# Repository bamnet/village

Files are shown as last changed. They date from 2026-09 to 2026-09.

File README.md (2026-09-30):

# Village Electric Light Department

_(village, for short)_

## Background

I have a collection of 1-2 dozen Department 56 lighted Christmas houses. The default
lighting solution has a big problem though: a house is either lit or not. Further,
the default technique of daisy-chaining all of the plugs together means the entire
village is typically on or off.

This is not very realistic, our winter Dickens Village is not North Korea.

## Goal

The Village Electric Light Department provides the ability for each house to be
individually dimmed and to have that brightness vary throughout the night. This
enables much more custom and realistic displays, with each house following its
own lighting pattern throughout the night and across different nights.

## Approach

### 2018?

In 2018 we built our first prototype. To do this, we bought an RGB LED strip and cut
it into individual segments. We soldered wires onto each segment, and wired them all
back into a TLC5947 controlled by an ESP32.

Each house got one cut segment of a 12 V analog (not individually addressable) RGBW
strip (Shiji Lighting SJ-10060-RGBW, 60 LEDs/m). A segment has 3 warm-white 5050 RGBW
LEDs. Each color channel runs its 3 LEDs in series with a current-limiting resistor
(150 ohm on G/B/W), roughly 20 mA per channel. The TLC5947 sank each channel's
current. See `archive/2018_led_segment.jpg`.

This was a good proof of concept, but the construction was quite messy with flexible
LED strip segments haphazardly positioned in the back / bottom lighting holes of the
houses, a messy breadboard wiring this all together, and standalone power supply.

### 2020?

We started cleaning up this design by introducing a circular PCB with LEDs that we
could fit into a 3D printer holder for each house. These could, in theory, be wired
back to a base station for control.

Ultimately, we never finished a working end-to-end design here, largely driven by
the manual work to solder connectors onto each of the PCBs and, more importantly,
the manual work to build custom cables to connect the PCBs back to the base station.

### 2025

We specified a two-board design (ESP32-S3 base station running WLED, plus a
daisy-chained 20 mm Pixel PCB with SK6812 RGBW LEDs) and started a controller
layout. Nothing was fabricated because we ran out of time.

## Specifications

Requirement keywords (MUST, SHOULD, MAY) follow RFC 2119. Items marked **TBD** are
open decisions.

### System

- The system MUST support 22 houses.
- Each house MUST be independently addressable, so its brightness can be set on
  its own. Addressing each LED within a house MAY be supported, but is not required.
- Houses SHOULD be daisy-chained, with the base station driving about 4 chains
  (roughly 6 houses per chain). This keeps cables short and the base station tidy.
  It is a preference, not a hard requirement: another topology is acceptable if
  it is clearly better.

### Physical layout

- Tentatively, the base station sits in the middle, between two shelves, with chains
  running outward on both sides.
- Houses are spaced about 1 ft (0.3 m) apart. A house-to-house cable of about 1 m
  gives enough slack.
- The farthest house is no more than 8 ft (2.4 m) from the base station.

### Light

As a winter village, each house MUST be lit using warm white light. Each house MAY
support RGB to fine tune the colors and do neat patterns.

The light should be bright, historically using a 5 - 6 watt C7 bulb @ 120 volts.
We obviously want to modernize this with an LED.

- Research (2026-09) shows small incandescent C7 bulbs are dim. Retail listings give
  a 4 W clear C7 as 16 - 19 lm, and a 5 W, 130 V-rated C7 as about 10 lm. LED
  "5 W equivalent" C7 bulbs claim 50 - 75 lm, but those figures are marketing, not
  measurements. The 2025 spec's "~60 lm" target is probably 3x too high.
- The 2018 prototype segment was bright enough, even with its poor LED placement on
  a flexible strip. It had 3 warm-white RGBW 5050 LEDs per house, each channel's LEDs
  in series at about 20 mA.
- Brightness target: warm-white output per house SHOULD match the 2018 segment,
  meaning 3 warm-white RGBW 5050 LEDs driven at about 16 - 20 mA.
- Each house MUST use one WS2814 as its driver. It is a 4-channel RGBW
  constant-current driver that WLED supports (configured as SK6812 RGBW type). Its
  outputs are fixed at 16.5 mA per channel, about 80% of the 2018 current.
  **TBD:** confirm this is bright enough.
- As of 2026-09-30, the original SOP-12 WS2814 (C965562) shows 0 stock at LCSC.
  The draft schematic uses the WS2814F (FSOP-8, C5446694, about 107,000 in stock).
  It has the same 16.5 mA outputs, the same 9 V DIN rating, and the same 12 V
  application circuit (2.7k to VDD, 0.1 uF). It has no backup data input (DIN2),
  so there is nothing to tie off. Its data order is W, R, G, B (datasheet p. 4).
  The WS2814A (SOP-8, C2920044, about 7,800 in stock) is the same die in a larger
  package. It is the fallback, with a standard SOIC-8 footprint.
- Decided (2026-09-30): the Pixel PCB uses the WS2814F. Its smaller body leaves
  more room for the LEDs on the 20 mm board.
- The WS2814F's FSOP-8 footprint (1.65 x 3.25 mm body, 2.85 mm lead span, 0.8 mm
  pitch) is not in KiCad's stock libraries, so we drew it. Once it's proven on a fabricated
  board, consider contributing it (and a WS2814 symbol) upstream to the KiCad
  libraries.
- Each channel drives 3 LEDs in series, and all 3 LEDs show the same color, with one
  address per house. The white channel MUST be warm white (2700 - 3000 K).
- LEDs SHOULD be 3 RGBW 5050 4-in-1 packages with a warm-white die, matching 2018.
  Fallback: 3 RGB LEDs plus 3 separate warm-white LEDs, which also allows a free
  choice of warm-white LED.
- As of 2026-09, LCSC has two warm-white 4-in-1 RGBW 5050 parts (SMD5050-8P, with
  a separate anode and cathode pin per color). Both are JLCPCB extended parts.
  Figures are from the datasheets, at 20 mA:
  - Honglitronic HL-5050RGBW-S1-A27 (C22470444): about 11,000 in JLCPCB stock.
    The "-A27" suffix is the datasheet's white bin A27, which is 2580 - 2870 K.
    That is slightly warmer than 2700 - 3000 K at the low end. White gives 7 - 9 lm,
    CRI 80 or better. Forward voltage is 2.8 - 3.4 V (W/G/B) and 1.8 - 2.4 V (R).
  - TCWIN TC5050RGBW3D06-4CSAR3-AFW324A (C784543): 2800 - 3200 K. White gives
    6 - 7 lm, CRI 80 - 85, with a forward voltage of 2.8 - 3.2 V. Stock is low
    (about 240 at JLCPCB, 860 at LCSC).
  - Cool-white variants that do not meet the spec: XINGLIGHT XL-5050RGBW
    (C7371891), TCWIN C784545 (6000 - 6500 K), and C784544 (3800 - 4200 K).
  **TBD:** choose between them. The Honglitronic part is preferred. One caution:
  its spec sheet (B-18-A-1651 rev A/2, 2019) has "Under Development" checked on
  its cover, not "Mass production". JLCPCB stocks it, so this is probably stale
  paperwork, but weigh it against TCWIN once the samples arrive.
- Heat is not expected to be a concern. The cut-up LED strip prototype ran without
  heat problems.
- Driver heat (estimated): 3 red LEDs drop only 5.4 - 7.2 V, which leaves up to
  about 6.6 V across the WS2814's red output (about 110 mW at 16.5 mA). The draft
  adds a 120 ohm ballast resistor (R4) on red to take about 2 V (33 mW) of that off
  the chip. With all four channels at full, the WS2814 then dissipates about
  0.2 W worst case. Warm-white-only use is well below this.
- The two LED candidates have different pinouts. Honglitronic has anodes on pins
  1/3/5/7 (W/B/G/R) and cathodes on 2/4/6/8. TCWIN has anodes on 1-4 (R/G/B/W)
  and cathodes on 8-5. The draft schematic follows the Honglitronic part.

### Interconnect

The lack of a practical cable solution is what stalled the 2020 attempt, so it is a
first-class requirement here.

- Cables MUST be off-the-shelf or easily purchasable. We MUST NOT need to crimp,
  solder, or otherwise build our own cables (the system needs about 24 of them).
- House-to-house links need cables of about 1 m. **TBD:** the length from the base
  station to the first house in each chain.
- The WS2814 datasheet specifies data runs of up to 2 m between two points without
  extra circuitry. The base-station-to-first-house run SHOULD stay within about 2 m.
  Otherwise the base station needs a stronger line driver.
- Cables MUST be standard 3-wire RC servo extension cables (JR/Futaba style, 2.54 mm
  pitch), bought ready-made. 1 m male-to-female cables are widely sold. 22 AWG is
  preferred over 26 AWG for lower voltage drop.
- Boards MUST use 2.54 mm pitch 1x3 headers: male pins for the incoming cable and a
  female socket for the outgoing cable. JLCPCB solders these through-hole parts.
- Pinout MUST put power on the middle pin, following the servo convention. Then a
  reversed plug swaps ground and data rather than shorting the supply. The design
  SHOULD tolerate a reversed plug without damage, using series resistors on data
  lines and similar measures. This is to be verified during design: in a reversal,
  a house's ground rides on the upstream data line, and the WS2814 data input is
  rated to only 9 V.
- Draft protection (Pixel PCB schematic v0.1, estimated rather than tested):
  - Reversed plug: this house's GND pin lands on the upstream data line. The
    return current of this house and every house downstream is about 2.6 mA per
    house through its 2.7k VDD resistor, so about 16 mA for 6 houses, since the
    LEDs stay dark with no valid data. Most of it flows through the upstream
    house's R3 (100 ohm) into the upstream WS2814's DOUT. For the first house in
    a chain, it flows into the Dig-Quad's output buffer instead. Only about
    1 - 2 mA goes through this house's R2 (1k) and D1. The part at risk is
    therefore the upstream driver. The datasheet rates DOUT sink current at 10 mA
    minimum at 0.4 V (p. 3), which is less than 16 mA. While the upstream DOUT is
    high, this house's ground rises to about 5 V. The current then splits between
    R2/D1 (about 5 mA) and the upstream chip's VDD. D1's job is to clamp DIN so it
    can't go below this house's lifted GND.
  - Offset plug (a socket shifted one pin over on the header): 12 V can land on the
    data pin. R2 limits this to about 7 mA into VDD through D1, so R2 dissipates
    about 45 mW (the 0402 is rated 62.5 mW). The pass/fail limit is the datasheet's
    VDD absolute maximum of 3.7 - 5.3 V (p. 2), so VDD must stay at or below 5.3 V.
  - Why keep D1: the datasheet limits logic input voltage to "VDD-0.7 ~ VDD+0.7"
    (p. 2). The lower bound is almost certainly a typo for -0.7 V. Either way, DIN
    may go only about 0.7 V beyond the rails. The BAT54S (Vf about 0.3 V) keeps
    DIN inside that window in both the reversed and offset cases. A series
    resistor alone would not.
  - DOUT keeps the datasheet's 100 ohm series resistor.
  - **TBD:** the R2 value. Test on the first fabricated Pixel boards (the LED
    samples on order don't include a WS2814F):
    - Reversed plug: check that the upstream DOUT and the Dig-Quad output survive
      and still work afterward.
    - Offset plug: measure VDD with 12 V on DATA_IN. It must stay at or below 5.3 V.
    No circuit change is planned until those results are in.
- Flat servo cable fits the original cord channel. It is thinner than the classic
  120 V lamp cord that already uses it.

### Power

- The system MUST use a 12 V supply. We chose 12 V over 5 V because of voltage drop.
  5 V SK6812 LEDs need at least 4.5 V at the last house, which leaves only about
  0.5 V for losses across a chain of servo cables. At 12 V, 3 white/blue/green LEDs
  in series need about 9 - 9.6 V (3.0 - 3.2 V each). Allowing for the driver output,
  that leaves roughly 1.5 V of headroom. These are estimates: the WS2814 datasheet
  does not specify the minimum output voltage it needs to regulate.
- Estimated load: about 66 mA per house with all four channels at full, so about 1.5 A
  (18 W) for 22 houses. With warm white only, it is about 16.5 mA per house, so about
  0.4 A.
- Estimated voltage drop: about 0.6 V at full RGBW for a 6-house chain on 26 AWG
  cable (about 2 m to the first house, then 1 m hops). This is within the headroom.
- For the prototype, power enters through the Dig-Quad's input screw terminals.
  **TBD:** a supply sized with margin (for example 12 V, 3 A or more).

### Pixel PCB

- The project targets KiCad 10. Files saved in KiCad 10 cannot be opened in
  KiCad 9.
- Draft schematic: `hardware/pixel/pixel.kicad_sch` (v0.1). It was authored in
  KiCad 9 format and is ERC clean in KiCad 9.0.2 and 10.0.6.
- Custom footprints live in the project library `hardware/pixel/village.pretty`
  (nickname `village`), since neither part is in KiCad's stock libraries:
  - `FSOP-8_1.65x3.25mm_P0.8mm` (U1, WS2814F). From the datasheet package drawing
    (V1.1, p. 6): 0.35 mm leads with 0.4 mm feet. The land pattern is 0.9 x 0.45 mm
    pads centered 2.6 mm apart (0.3 mm toe, 0.2 mm heel).
  - `LED_Honglitronic_HL-5050RGBW_5.0x5.0mm_P1.2mm` (D2-D4). This is the
    manufacturer's recommended land pattern (spec B-18-A-1651 rev A/2, p. 3):
    1.1 x 0.54 mm pads, 2.83 mm inner gap, 1.2 mm pitch. Pads are numbered as in the
    datasheet's top view: anodes 1/3/5/7 on the right, cathodes 2/4/6/8 on the
    left, pin 1 at the top right. The part's corner mark sits at pin 2.
  - **TBD:** the LED datasheet's "bottom view" labels the pins the same as its top
    view, not mirrored, so one of the two views is wrong. A mirrored footprint
    would put every LED in backwards. Before ordering boards, check a sample with
    a multimeter in diode mode: with the corner mark at the top left, looking at
    the lens, the top-right lead should be the white anode (+).
  - **TBD:** both are unproven until a fabricated board is assembled and works.
    The TCWIN LED would need its own footprint, because its pad numbering differs.
- In order to fit the 3D-printed holder that sits in each house's lighting hole,
  the per-house PCB ("Pixel PCB") MUST be a circle no bigger than 20 mm in diameter.
  This is small, but large enough to fit several LEDs as needed.
- The lighting hole in the house itself is slightly larger than the holder hole. The
  hole size is broadly consistent across houses (the original lights are
  interchangeable). **TBD:** the measured house hole size.
- Some houses have the lighting hole in the back and some in the bottom. For bottom
  holes, the original clip-in lamp sits in the hole and its cord leaves sideways,
  flush with the base, through a notch and cord channel in the house base.
- For bottom holes, the assembly can extend up to about 1 in (25 mm) into the house.
- A daisy-chained house has two cables (in and out). Both MUST fit through the notch
  and cord channel. Two flat servo cables fit, since a classic 120 V lamp cord does.
- LEDs MUST be on the top side, clustered near the center. Headers (through-hole)
  go on the bottom side.
- All surface-mount parts, the WS2814 included, SHOULD also go on the top side. That
  keeps assembly to one surface-mount side, which is simpler and cheaper. Moving the
  WS2814 to the bottom is allowed if the LEDs don't fit otherwise, but it requires
  JLCPCB two-sided (Standard) assembly. **TBD:** settle this during layout, once the
  LED part is chosen.
- Through-hole header pins and solder joints come out on the LED side. Headers
  MUST sit near the rim, with a centered keep-out for the LEDs.
- Headers SHOULD be right-angle, mounted side by side on the bottom, with both
  pointing the same way (toward the cord notch). The plugs then lie flat under the
  board. This gives a much lower profile than vertical headers, and both cables
  already point where they need to go. JLCPCB-assemblable candidates: male C492411
  and female C2897385. If two plugs don't fit side by side on the 20 mm board, fall
  back to vertical headers. **TBD:** confirm the fit with real servo plugs (the
  width is estimated at about 8 mm each).
- Provisional layout (placed and routed, pending real plug dimensions):
  `hardware/pixel/pixel.kicad_pcb`.
  - The board is a 20 mm circle. The cord notch is taken to be at the south
    (+Y) edge.
  - J1 and J2 are on the bottom side, with pin rows side by side about 4 mm north
    of center. Their bodies point south and run under the board, so the plugs
    mate near the south rim and lie flat. This works because the headers and
    plugs are on the bottom while every other part is on the top, so the header
    bodies can sit under the top-side parts.
  - This relaxes "headers near the rim". The pin rows sit just north of the
    LEDs, and the LED cluster sits about 2.5 mm south of center.
  - The header rows are 8.9 mm apart, center to center. KiCad's stock
    footprints need at least 8.62 mm, which is slightly more than the estimated
    8 mm plug width.
  - J1 and J2 use KiCad's stock right-angle footprints. Checked against the LCSC
    drawings on 2026-09-30, and the copper matches:
    - J1, male (XFCN PZ254R-11-03P, C492411): Ø1.02 mm holes and 0.64 mm square
      pins (0.91 mm across the corners, so they fit the 1.0 mm drill). The
      body's front face is 4.4 mm from the pin row, and the pin tips are at
      10.4 mm (KiCad draws 4.04 mm and 10.04 mm).
    - J2, female (HCTL PM254-1-03-W-8.5, C2897385): Ø1.02 mm holes. The 8.5 mm
      body ends 10.2 mm from the pin row (KiCad draws 10.03 mm), and the body is
      8.02 mm wide (KiCad draws 7.62 mm).
    - KiCad's courtyards still cover both real bodies. With the rows 8.9 mm apart,
      the bodies are about 1.1 mm apart.
    - The pin tails are 3.0 and 3.2 mm long, so on a 1.6 mm board they stick up
      about 1.4 - 1.6 mm on the LED side.
  - Pin order: the stock footprints put J1's pin 1 at the west end and J2's pin 1
    at the east end, so the two GND pins are adjacent. Neither part is polarized,
    so this only decides which way up each cable plugs in.
  - Silkscreen markings for plugging in and for JLCPCB's assembly review:
    - Bottom: a filled triangle points at each header's pin 1 (data), with "+" and
      "-" at the other pins. These shapes read the same whether or not they are
      mirrored.
    - Bottom: "JLCJLCJLCJLC" marks where JLCPCB should print its order number.
      When ordering, choose "Specify a location" for the order number. Otherwise
      it could land among the LEDs.
    - Top: "v0.1", and a pin-1 dot inside U1's outline. The footprint's pin-1
      silkscreen line is clipped by J1's GND pad, so without the dot the top and
      bottom lines would look alike.
    - The LEDs keep their pin-1 tick. D1 uses KiCad's stock SOT-23 outline.
  - On the top side, the LEDs follow the chain +12V -> D2 (east, rot 90) -> D3
    (south, rot 0) -> D4 (west, rot 270) -> U1. Each LED faces the side that
    connects to the next LED toward it, so each group of four color nets between
    LEDs fans diagonally with no crossings. D4's R/G/B cathodes sit just below
    U1's matching outputs. U1 is between D4 and D2, with R4 on the red output and
    C1 beside the VDD pin. D1, R1, C2 and R2 sit above the header pin rows.
  - Routed with Freerouting 2.4.1: 4 vias. +12V and GND are 0.4 mm (a Power
    netclass), because up to ~0.4 A passes through to the rest of the chain.
    Signals are 0.2 mm. VDD narrows to 0.15 mm around U1, and the board minimum
    is set to 0.15 mm to allow it.
  - DRC: 0 errors, 0 unconnected. JLCPCB's limits are enforced by
    `pixel.kicad_dru` and the board setup.
  - Routing workflow: export the DSN with KiCad's Python module
    (`pcbnew.ExportSpecctraDSN`). Route with Freerouting's bundled launcher,
    because the standalone jar needs Java 25. Import the session in KiCad with
    File -> Import -> Specctra Session. Konnect's own DSN export refuses this
    board (round outline, back-side headers, custom rules).
  - **TBD:** revisit the header positions once real plugs are measured.
- The connector, the holder, or both SHOULD let the cables make the turn into the
  channel without stressing the connectors or their solder joints.

### Base station

- For prototyping, we will buy an off-the-shelf WLED controller instead of designing
  one, so the effort goes into the Pixel PCB. A custom base station is deferred. The
  requirements below still apply to whatever we use. The prototype controller is the
  QuinLED Dig-Quad (pre-assembled): 4 level-shifted outputs, 12 V capable, and a
  plug-in fuse per pair of outputs, which should be sized to protect the servo cables.
- For the prototype, each chain connects to the Dig-Quad's screw terminals using a
  servo extension cable cut in half, with the ends stripped. This is an accepted
  exception to the no-built-cables rule, since it needs no soldering or crimping.
- The base station does not have any sizing constraints.
- It MUST be compatible with [WLED](https://kno.wled.ge/) (ESP32-based), so we can get
  started quickly. Custom firmware is a future goal and is out of scope for now.
- Because of that, the LED or driver IC on the Pixel PCB MUST be one of the LED
  types WLED supports.
- The WS2814 data input needs a logic-high of at least 0.7 x VDD (about 3.5 V), which
  is above the ESP32's 3.3 V. Each chain output MUST go through a 5 V level shifter
  (for example 74AHCT125) and a series resistor.
- It MUST have enough chain outputs for the chosen topology (about 4).
- No extra features, such as sensors or current monitoring, are required.

### Manufacturing

- Both boards SHOULD be assembled by JLCPCB, as completely as possible, including the
  connectors. Hand soldering MUST be kept to a minimum.
- Minimize cost per house, but pay for factory assembly rather than hand work where
  there is a trade-off.

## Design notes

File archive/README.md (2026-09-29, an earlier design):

# Archive

This folder contains archive material from previous incarnations of this project.

Do NOT assume it is current. Do NOT assume it is  correct. Do NOT assume it is valid.
It is purely a record of historical work that may or may not be interesting to research.

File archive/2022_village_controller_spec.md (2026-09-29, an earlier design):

**Request:** Create circuit schematic and PCB design & layout.

**Project Goal**: Independently control 6 x RGBW LED boards using an ESP32 microcontroller.

# Module Diagram

# Modules

## LED Driver

For my prototyping, I’ve been using this TLC5947 breakout board from Adafruit and it works great: [https://www.adafruit.com/product/1429](https://www.adafruit.com/product/1429).

I’m open to other LED drivers as long as they allow me to control 24 channels (6 RGBW LEDs) @ \~12V. 

My code currently assumes the TLC5947 is connected as follows:

ESP IO5 \-\> TLC XLAT  
ESP IO18 \-\> TLC SCLK  
ESP IO19 \-\> TLC SIN

*Feel free to suggest alternative suitable pins if it makes the routing easier.*

## LED1 \- LED6

LEDS1-6 will be connected via [Molex 105310-2106](https://www.molex.com/molex/products/part-detail/pcb_headers/1053102106) with the following pinouts

| MOLEX Pin | LED1 | LED2 | LED3 | LED4 | LED5 | LED6 |
| :---: | ----- | ----- | ----- | ----- | ----- | ----- |
| **1** | \- | \- | \- | \- | \- | \- |
| **2** | OUT0 | OUT4 | OUT8 | OUT12 | OUT16 | OUT20 |
| **3** | OUT1 | OUT5 | OUT9 | OUT13 | OUT17 | OUT21 |
| **4** | **\+12V** | **\+12V** | **\+12V** | **\+12V** | **\+12V** | **\+12V** |
| **5** | OUT2 | OUT6 | OUT10 | OUT14 | OUT18 | OUT22 |
| **6** | OUT3 | OUT7 | OUT11 | OUT15 | OUT19 | OUT23 |

## ESP32

To avoid having to design an antenna and deal with certification, a module like **ESP32-WROOM-32E** can be used.

## Power

Each LED requires \~12V.  The ESP32 requires 3.3V \- 5V.

*Open Question: Could this be powered by a USB C charger or does it have to use a regular DC Power connector?*

# Prototype

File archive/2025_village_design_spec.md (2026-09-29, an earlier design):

# **Project Summary**

# **Project Summary: Custom 8-Channel ESP32-S3 LED Controller PCB Design**

## **I. Project Goal**

Design two related PCBs for a miniature village LED lighting system, utilizing individually addressable SK6812 RGBW (Warm White) LEDs. The primary focus is on robust design (THT connectors for durability) and cost-effective manufacturing (JLCPCB Basic Parts).

## **II. Key Deliverables (Two Boards)**

### **A. Board A: Main Dock (Controller)**

| Feature | Specification | Rationale |
| :---- | :---- | :---- |
| **Microcontroller** | ESP32-S3 (WROOM-1 Module) | Runs WLED firmware; must include USB-C, Boot/Reset buttons. |
| **Power Input** | 5V DC Barrel Jack (5.5mm x 2.1mm) | High current, max 8A. Must include Reverse Polarity Protection (RPP) and a 10A fuse/PTC. |
| **Outputs** | 8x JST-PH 3-Pin Connectors (Vertical) | Supports 8 independent chains. Max \$\\sim\$2A per port. |
| **Data Integrity** | Level Shifting required (2x 74AHCT125) | To boost 3.3V logic to 5V for reliable long-chain operation. |

### **B. Board B: House LED Board (Pixel PCB)**

| Feature | Specification | Rationale |
| :---- | :---- | :---- |
| **Shape/Size** | **Circular, 20mm Diameter** | Critical for fitting into standard village house base holes. |
| **LEDs** | 3x SK6812 RGBW (Warm White) | Tightly clustered, 3535 size preferred, to act as a single point light source. |
| **Connectors** | 2x JST-PH 3-Pin (Input/Output) | **Through-Hole (THT)** required for mechanical durability during frequent plugging/unplugging. |
| **Layout** | **Component Split Mandatory** | LEDs on one side (Top), Connectors/Passives on the opposite side (Bottom). |
| **Pass-Through Current** | Max 1.0A through VCC/GND traces | Must support up to 5 downstream houses. |

## **III. Manufacturing Constraints (JLCPCB Focus)**

* **Cost Optimization:** Component selection **MUST** prioritize **JLCPCB Basic Parts** (especially for resistors, capacitors, and ICs) to minimize assembly costs.  
* **Deliverables:** Full set of fabrication files (Gerbers, BOM with LCSC P/Ns, CPL file) and source files (KiCad or EasyEDA).  
* **Goal:** Production-ready files that can be uploaded directly to the JLCPCB SMT assembly service.

# **Details**

# **Custom PCB Design for Miniature Collectible Village LED Lighting System**

## **1\. Project Overview**

I am building a custom lighting solution for miniature collectible village houses (such as those made by Department 56 or Lemax). The goal is to replace standard incandescent bulbs with individually addressable **SK6812 RGBW (Warm White)** LEDs.

I need a design for a **Main Docking Board** and a small **House LED Board**. I plan to have these manufactured and assembled by **JLCPCB**.

## **2\. System Architecture**

The system uses a **Main Dock** that drives 8 chains of houses.

* **Topology:** **Multi-Channel Daisy Chain**. The Dock provides 8 ports. The user connects multiple houses (daisy-chained) to each port.  
* **Voltage:** 5V DC System.  
* **LED Type:** SK6812 RGBW (Warm White).

## **3\. Scope of Work (Deliverables)**

### **Board A: The Main Dock (Controller Board)**

* **Function:** Main controller that powers the village and runs WLED software.  
* **Microcontroller:** **ESP32-S3 (WROOM-1 Module)**.  
  * Must include USB-C for programming/power and Boot/Reset buttons.  
  * **Note:** Designer may use the ESP32-S3 **Native USB** interface (direct USB D+/D- connection) to save BOM cost, or a standard USB-to-UART bridge.  
* **Power Input:** 5V DC via a DC Barrel Jack (5.5mm x 2.1mm DC Barrel Jack, High current, approx 8A max).  
  * Include **Reverse Polarity Protection** (e.g., P-Channel MOSFET).  
  * Include **Fuse** (10A SMD Fuse holder or resettable PTC (e.g., 10A rating).  
  * **Bulk Capacitance:** 1000uF or more to handle transients.  
* **Outputs:** 8x **JST-PH 3-Pin** Connectors (Vertical).  
  * *Logic:* These 8 ports are driven by 8 independent GPIOs from the ESP32.  
  * *Level Shifting:* Use **2x 74AHCT125** (Quad Level Shifter) to boost 3.3V logic to 5V for all 8 ports.  
  * *Power Distribution:* Each port must have a capable 5V/GND trace to handle \~2A per port.  
* **Extra Features:**  
  * 1x Power LED.

### **Board B: The House LED Board (Pixel PCB)**

* **Function:** A tiny PCB that sits inside the house, acting as the light source and pass-through.  
* **Components:**  
  1. **LEDs:** 3x **SK6812 RGBW** (Warm White) Surface Mount LEDs.  
     * *Size Preference:* **3535 size** is preferred to save space on the small board.  
     * *Arrangement:* **Tightly clustered in the center** (e.g., triangle formation) to act as a single point light source and ensure light projects up into the house cavity without being blocked by the base hole rim.  
     * *Logic:* Daisy-chained on-board (Input \-\> LED1 \-\> LED2 \-\> LED3 \-\> Output).  
  2. **Capacitor:** 100nF decoupling per LED.  
* **Connectors (Pass-through):**  
  * **Input:** 1x **JST-PH 3-Pin** (Male/Header) \- From Dock/Previous House.  
  * **Output:** 1x **JST-PH 3-Pin** (Male/Header) \- To Next House.  
  * *Connector Standard:* Use **Through-Hole (THT)** JST-PH 3-Pin Receptacles/Headers (Right Angle preferred if space allows, otherwise Vertical). THT is requested for mechanical durability.  
  * *Pinout:* VCC (Pin 1), Data (Pin 2), GND (Pin 3). Data trace connects Pin 2 Input to LED1 DIN. LED3 DOUT connects to Pin 2 Output. VCC/GND rails are shared.  
* **Physical:**  
  * **Shape/Size:** Circular, 20mm diameter. This shape ensures compatibility with standard circular holes found in the base of many village houses.  
  * **Component Placement:** **MANDATORY:** LEDs must be placed exclusively on one side (Top Layer), and Connectors must be placed exclusively on the opposite side (Bottom Layer).  
  * **Color:** White Soldermask (to reflect light).

## **4\. Manufacturing Requirements (JLCPCB Specifics)**

* **Parts Selection:** Component selection **MUST** prioritize "Basic Parts" from the **JLCPCB/LCSC library** (especially for resistors/capacitors) to minimize assembly costs.  
* **Deliverables:**  
  1. **KiCad or EasyEDA Source Files**.  
  2. **Gerber Files** (ready for production).  
  3. **BOM (Bill of Materials)** with LCSC Part Numbers.  
  4. **CPL (Centroid/Pick & Place File)**.

## **5\. Notes for the Designer**

* **Space Constraints:** Board B is very small (20mm). Please ensure the **Through-Hole pins** from the connectors on the bottom layer do not interfere with the LED footprints on the top layer. (The 3535 LEDs should be centered, allowing THT pins to occupy the outer rim).  
* **Current Traces:** Board A's power traces must be robust. Board B's VCC/GND traces must handle pass-through current for up to 5 downstream houses (Max 1.0A pass-through). Designer must size VCC/GND traces accordingly.  
* **LED Brightness:** The design uses 3 LEDs to ensure brightness matches/exceeds the original incandescent bulbs (approx 60 Lumens total).

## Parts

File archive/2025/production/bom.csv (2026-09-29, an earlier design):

Designator | Footprint | Quantity | Value | LCSC Part #
C1, C3, C8, C9 | 0402 | 4 | 100n
C2 | 0603 | 1 | 10u
C4, C7 | 0603 | 2 | 1u
C5, C6 | 0805 | 2 | 22u
C9X | 0402 | 1 | 0.1u
D1 | D_SOD-123 | 1 | 1N5817
D2, D4, D6 | D_SOD-923 | 3 | ESD3.3
D3 | 0603 | 1 | GREEN
D5 | LED_Cree-PLCC4_3.2x2.8mm_CCW | 1 | CLV1L-FKB
D5X, D7, D8 | LED_SK6812_PLCC4_5.0x5.0mm_P3.2mm | 3 | SK6812
F1 | 1206 | 1 | Polyfuse 1A
FB1 | 0805 | 1 | BLM21PG220
H3_2, H3 | MountingHole_3.2mm_M3 | 2 | MountingHole
J1 | USB_C_Receptacle_HRO_TYPE-C-31-M-12 | 1 | USB_C_Receptacle_USB2.0
J2 | PinHeader_2x05_P2.54mm_Vertical | 1 | Pin_2x5
J3 | PinHeader_2x03_P2.54mm_Vertical | 1 | Conn_02x03_Odd_Even
J5 | PinHeader_1x04_P2.54mm_Vertical | 1 | Conn_01x04
J6, J7, J8, J9 | JST_PH_B3B-PH-K_1x03_P2.00mm_Vertical | 4 | jst connector
R1, R2, R7, R8, R9Y | 0402 | 5 | 10K
R3, R4 | 0402 | 2 | 5.1K
R5, R6_2, R7_2, R9 | 0402 | 4 | 1K
R6_3, R7_3, R9X | 0402 | 3 | 33R
R6 | 0402 | 1 | 2K2
SW1 | SW_SPST_B3U-1000P | 1 | RESET
SW2 | SW_SPST_B3U-1000P | 1 | BOOT
SW3 | SW_Tactile_SPST_Angled_PTS645Vx31-2LFS | 1 | USER_SW
U1 | SOT-23-6 | 1 | USBLC6-2SC6
U2 | ESP32-S3-WROOM-1 | 1 | ESP32-S3-WROOM-1-N16
U3 | SOT-223-3_TabPin2 | 1 | LM1117-3.3
U4 | DFN-6-1EP_3x3mm_P1mm_EP1.5x2.4mm | 1 | Si7021-A20
U5_2 | SOIC-8_3.9x4.9mm_P1.27mm | 1 | INA219AxD
U5, U6 | SOIC-14_3.9x8.7mm_P1.27mm | 2 | 74AHCT125

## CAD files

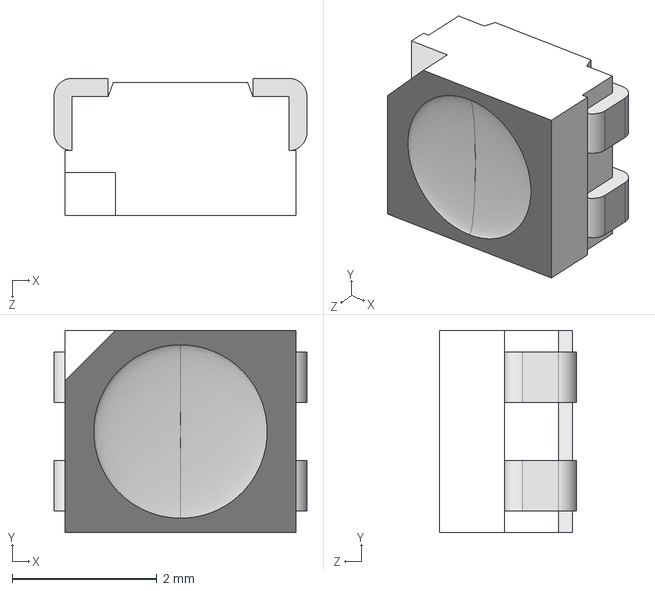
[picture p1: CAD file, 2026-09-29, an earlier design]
archive/2025/CLV1AFKB.STEP
3.50 x 2.80 x 1.90 mm

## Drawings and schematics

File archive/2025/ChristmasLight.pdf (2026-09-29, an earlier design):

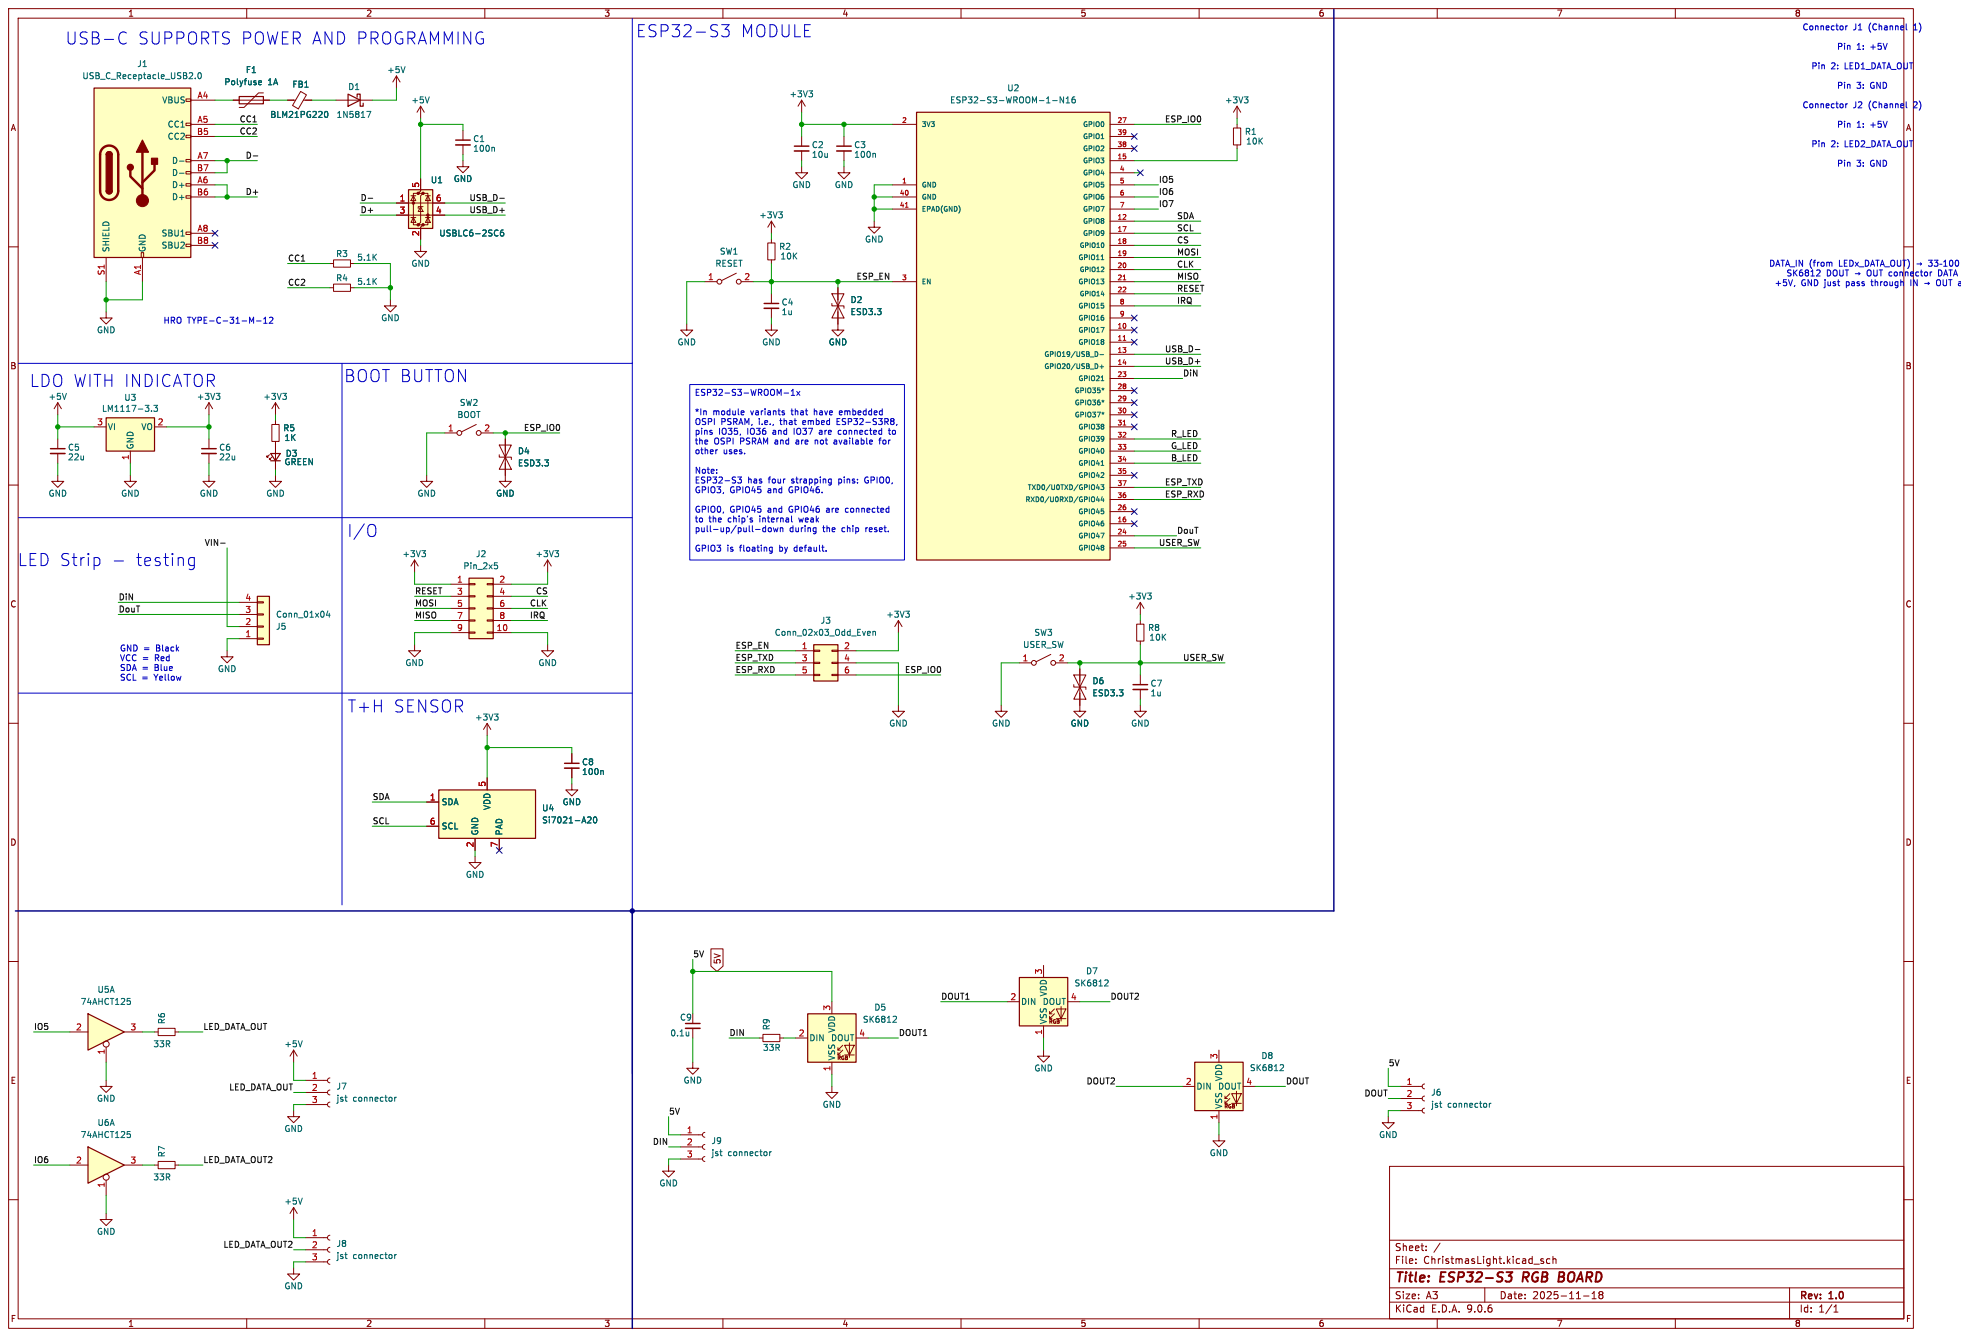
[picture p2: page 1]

USB-C SUPPORTS POWER AND PROGRAMMING

DATA_IN (from LEDx_DATA_OUT) þÿ!’þÿ33 100 þÿ©þÿ!’SK6812 DIN

GND = Black VCC = Red SDA = Blue SCL = Yellow LED Strip - testing

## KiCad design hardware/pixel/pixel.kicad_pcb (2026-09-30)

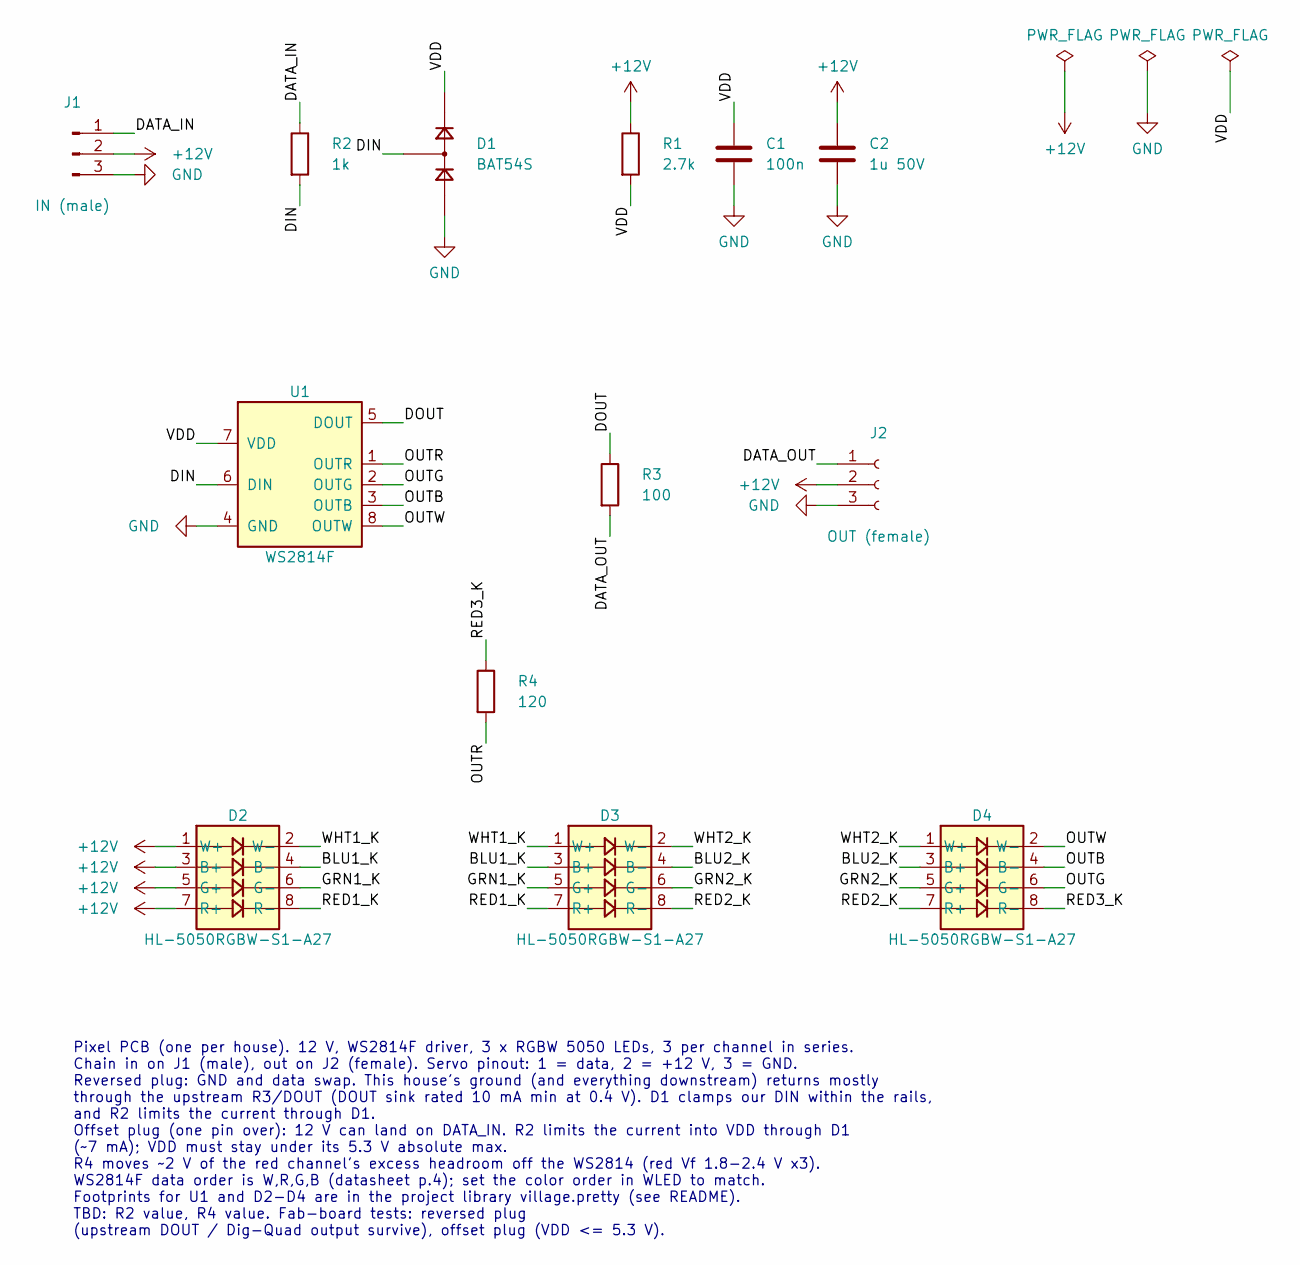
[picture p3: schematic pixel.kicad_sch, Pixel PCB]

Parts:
C1: 100n; C_0402_1005Metric; MPN CL05B104KO5NNNC; LCSC C1525
C2: 1u 50V; C_0603_1608Metric; MPN CL10A105KB8NNNC; LCSC C15849
D1: BAT54S; SOT-23; MPN BAT54SLT1G; LCSC C19726
D2, D3, D4: HL-5050RGBW-S1-A27; LED_Honglitronic_HL-5050RGBW_5.0x5.0mm_P1.2mm; MPN HL-5050RGBW-S1-A27; LCSC C22470444
J1: IN (male); PinHeader_1x03_P2.54mm_Horizontal; MPN PZ254R-11-03P; LCSC C492411
J2: OUT (female); PinSocket_1x03_P2.54mm_Horizontal; MPN PM254-1-03-W-8.5; LCSC C2897385
R1: 2.7k; R_0603_1608Metric; MPN 0603WAF2701T5E; LCSC C13167
R2: 1k; R_0402_1005Metric; MPN 0402WGF1001TCE; LCSC C11702
R3: 100; R_0402_1005Metric; MPN 0402WGF1000TCE; LCSC C25076
R4: 120; R_0402_1005Metric; MPN 0402WGF1200TCE; LCSC C25079
U1: WS2814F; FSOP-8_1.65x3.25mm_P0.8mm; MPN WS2814F; LCSC C5446694

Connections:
+12V: C2.1, D2.1 (W+), D2.3 (B+), D2.5 (G+), D2.7 (R+), J1.2, J2.2, R1.1
/BLU1_K: D2.4 (B-), D3.3 (B+)
/BLU2_K: D3.4 (B-), D4.3 (B+)
/DATA_IN: J1.1, R2.1
/DATA_OUT: J2.1, R3.2
/DIN: D1.3 (COM), R2.2, U1.6 (DIN)
/DOUT: R3.1, U1.5 (DOUT)
/GRN1_K: D2.6 (G-), D3.5 (G+)
/GRN2_K: D3.6 (G-), D4.5 (G+)
/OUTB: D4.4 (B-), U1.3 (OUTB)
/OUTG: D4.6 (G-), U1.2 (OUTG)
/OUTR: R4.2, U1.1 (OUTR)
/OUTW: D4.2 (W-), U1.8 (OUTW)
/RED1_K: D2.8 (R-), D3.7 (R+)
/RED2_K: D3.8 (R-), D4.7 (R+)
/RED3_K: D4.8 (R-), R4.1
/VDD: C1.1, D1.2 (K), R1.2, U1.7 (VDD)
/WHT1_K: D2.2 (W-), D3.1 (W+)
/WHT2_K: D3.2 (W-), D4.1 (W+)
GND: C1.2, C2.2, D1.1 (A), J1.3, J2.3, U1.4 (GND)

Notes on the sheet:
Pixel PCB (one per house). 12 V, WS2814F driver, 3 x RGBW 5050 LEDs, 3 per channel in series. Chain in on J1 (male), out on J2 (female). Servo pinout: 1 = data, 2 = +12 V, 3 = GND. Reversed plug: GND and data swap. This house's ground (and everything downstream) returns mostly through the upstream 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

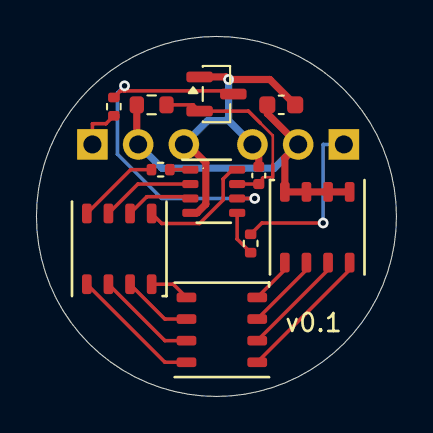
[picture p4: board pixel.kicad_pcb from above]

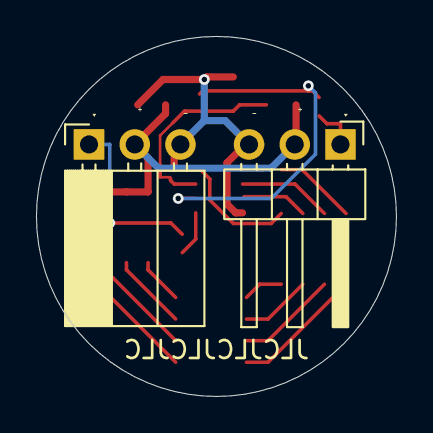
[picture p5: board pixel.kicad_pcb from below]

Board: 2 copper layers, 20.0 x 20.0 mm, 13 parts (2 on the bottom side), 20 nets.

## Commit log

2026-09-29 Add archival material
    [CLV1AFKB.STEP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]
2026-09-29 Archival photo of initial LED segment
2026-09-29 Clarify specification: 12 V WS2814 pixels over servo cables
    Record requirements from the spec review: 22 houses on ~4 daisy chains,
    off-the-shelf servo extension cables with 2.54 mm headers, 12 V supply,
    one WS2814 per house driving 3 series RGBW LEDs, brightness matched to
    the 2018 prototype, mechanical constraints for bottom/back holes, and
    JLCPCB assembly. Open decisions are marked TBD.
2026-09-29 Enable kicad-happy plugin for this project
    Declare the aklofas/kicad-happy marketplace and enable its plugin at
    project scope, so the KiCad analysis and LCSC/JLCPCB sourcing skills
    are available to anyone working in this repo.
    Claude-Session: https://claude.ai/code/session_01VgDz1r9wRYGVXFnVgHwR28
2026-09-29 Spec: warm-white LED candidates, Dig-Quad controller, right-angle headers
    Record the LCSC search for warm-white RGBW 5050 4-in-1 LEDs: Honglitronic
    HL-5050RGBW-S1-A27 (C22470444, bin 2580-2870 K) is preferred over TCWIN
    C784543 (2800-3200 K, low stock); the final choice stays TBD pending
    samples. Use a pre-assembled QuinLED Dig-Quad as the prototype base
    station, fed by halved servo extension cables. Prefer right-angle headers
    side by side on the bottom, falling back to vertical if the plugs don't
    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
2026-09-30 Pixel PCB: draft schematic v0.1
    Add hardware/pixel KiCad 9 project with the per-house schematic:
    WS2814F driver, 3 x RGBW 5050 LEDs (3 in series per channel), right-angle
    servo headers, DIN series resistor + BAT54S clamp for reversed/offset
    plugs, and a red-channel ballast resistor.
    The SOP-12 WS2814 (C965562) is out of stock at LCSC, so the draft uses
    the pin-compatible-in-function WS2814F (FSOP-8, C5446694). README updated
    with the switch, protection analysis, driver heat, and LED pinout notes.
    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
    [pixel.kicad_sch]
2026-09-30 Pixel schematic: fix KiCad load error, use stock symbols, tidy layout
    - Escape newlines in the notes text; KiCad 9.0.2 refused to load the file.
    - Copy Device/Connector/power symbols verbatim from KiCad's stock libraries.
    - Leave U1/LED footprints blank until the custom footprints exist.
    - Rotate power symbols along their stubs, give PWR_FLAGs their own group,
    and space parts so labels don't overlap.
    ERC in KiCad 9.0.2: 0 errors, 0 warnings. The kicad-cli netlist matches
    the intended connectivity (20 nets).
    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
    [pixel.kicad_sch]
2026-09-30 README: decide on the WS2814F; note upstream footprint idea
    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
2026-09-30 README: reversal test needs fabricated boards, not the LED samples
    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
2026-09-30 Address review: fix reversed-plug analysis, add .gitignore, review nits
    - Rewrite the reversed-plug explanation (README and sheet note): most of
    the return current flows through the upstream R3 into the upstream
    DOUT (10 mA min sink at 0.4 V), or into the Dig-Quad for the first
    house. R2/D1 carry only 1-2 mA.
    - Fab-board test TBD now checks that the upstream DOUT/Dig-Quad output
    survives a reversal, and that VDD stays <= 5.3 V (abs max) with 12 V on
    DATA_IN.
    - Cite the DIN input-voltage rating as the reason to keep D1.
    - Note the Honglitronic spec sheet's "Under Development" status.
    - C2: 1 uF 0402/25 V -> 1 uF 0603/50 V (C15849, basic) for DC bias.
    - Rename the LED chain nets (RED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
    [pixel.kicad_sch]
2026-09-30 Pixel PCB: add FSOP-8 and HL-5050RGBW footprints
    Project footprint library hardware/pixel/village.pretty, registered
    as 'village'. FSOP-8 follows the WS2814F package drawing (V1.1 p.6);
    the LED uses Honglitronic's recommended land pattern (B-18-A-1651
    p.3). Also corrects the README's FSOP-8 body size (2.85 mm is the
    lead span; the body is 1.65 x 3.25 mm) and adds a TBD to check the
    LED pin mirroring on a sample before fab.
2026-09-30 Pixel PCB: assign custom footprints to U1 and D2-D4
    [pixel.kicad_sch]
2026-09-30 Pixel PCB: add board with 20 mm round outline and footprints from schematic
    [pixel.kicad_pcb]
2026-09-30 Pixel PCB: commit KiCad board settings; ignore KiCad local history
2026-09-30 Pixel PCB: provisional fit-study placement
    Headers on the bottom along the south rim (estimated plug width),
    LEDs in a centered triangle, U1 and passives around them. No
    courtyard overlaps; only unrouted-connection DRC errors remain.
    Also refreshes all footprints from their libraries (the schematic
    import had left them out of sync).
    [pixel.kicad_pcb]
2026-09-30 Pixel PCB: headers under the board, LEDs spaced out
    Adopts the hand-tuned layout: header pin rows north of center with
    their bodies running under the board, since only the headers are on
    the bottom. Gives the LEDs 0.5-1 mm between bodies. Passives placed
    around it; C1 sits beside U1's VDD pin. Placement score 100; only
    unrouted-connection DRC errors remain.
    [pixel.kicad_pcb]
2026-09-30 Pixel PCB: enforce JLCPCB limits in DRC; 0.15 mm silkscreen on custom footprints
    pixel.kicad_dru adds JLCPCB's via (0.15 mm) and plated-pad (0.18 mm)
    annular-ring minimums and silkscreen text limits (1.0 mm height,
    0.15 mm stroke). The FSOP-8 and LED footprints now use 0.15 mm
    silkscreen lines, JLCPCB's minimum, and the placed copies are
    refreshed.
    [pixel.kicad_pcb]
2026-09-30 Pixel PCB: hide reference labels on silkscreen
    The 20 mm board has no room for readable reference text. The labels stay on
    the footprints (BOM and placement files are unaffected), just hidden.
    [pixel.kicad_pcb]
2026-09-30 Pixel PCB: rotate LEDs so each group of LED nets fans without crossing
    The LED chain +12V -> D2 -> D3 -> D4 -> U1 now runs east -> south -> west.
    D2 (rot 90) sends its cathodes south to D3's anode column, and D3
    (rot 0) sends its cathodes west to D4's anode row. D4 (rot 270) puts
    its R/G/B cathodes directly below U1's matching output pins. U1 moves
    up, and R4, C1 and R3 are re-fitted. Placement score 100.
    [pixel.kicad_pcb]
2026-09-30 Pixel PCB: Power netclass (0.4 mm) for +12V and GND
    +12V and GND pass up to ~0.4 A through each house to the rest of
    the chain.
2026-09-30 Pixel PCB: route with Freerouting
    Autorouted with Freerouting 2.4.1: 88 segments, 4 vias, 0.4 mm on
    +12V/GND. The LED groups fan diagonally between the rotated
    LEDs. VDD narrows to 0.15 mm around U1, so the board minimum track
    width is now 0.15 mm (JLCPCB's typical signal width; their limit is
    0.10 mm). DRC: 0 errors, 0 unconnected.
    [pixel.kicad_pcb]
2026-09-30 README: describe routed Pixel PCB layout and routing workflow
2026-09-30 README: check header footprints against the LCSC connector drawings
2026-09-30 Pixel PCB: silkscreen markings for plugging in and JLCPCB assembly review
    Bottom: pin-1 (data) triangles and +/- marks at each header (shapes, so
    they read correctly on the back), and a JLCJLCJLCJLC order-number
    placeholder. Top: revision v0.1, and a pin-1 dot inside U1 because J1's
    pad clips the footprint's own pin-1 line. The schematic note no
    longer lists the footprints as TBD. DRC: 0 errors; ERC clean.
    [pixel.kicad_pcb, pixel.kicad_sch]
2026-11-07 Pixel PCB: mark the LED's real corner and record the sample test
    Multimeter tests of C22470444 and C784543 samples showed that the
    Honglitronic datasheet's top view is correct, so the footprint pads were
    already right. The LED's corner mark sits at pin 2 (white cathode), but the
    footprint's silkscreen tick and Fab chamfer marked pin 1. Move both to the
    pin 2 corner so that placement review matches the physical part, and
    refresh D2-D4 from the library. Pad positions and nets are unchanged, and
    DRC is unchanged (0 errors, the same 21 warnings).
    README: choose C22470444 (warmer white), close the mirroring TBD, and note
    that both candidates match physically and differ only in pin numbering.
    Co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
2026-11-07 README: record the measured width of a C2897385 sample
2026-11-07 Pixel PCB: JLCPCB CPL rotation corrections and export notes
    U1 (FSOP-8) needs +270 degrees and D1 (SOT-23) +180 degrees to match JLCPCB's
    footprints for C5446694 and C19726. Both values came from comparing pad layouts
    with JLCPCB's EasyEDA footprints. The same comparison reproduces Konnect's
    preview-verified SOIC-8 rule. The LEDs need no correction.
2026-11-07 Pixel PCB: track the v0.1 JLCPCB package as a release
    Add the exported Gerbers, BOM and CPL under production/v0.1 with a manifest
    that records the source commit, file hashes, export checks, and a section for
    the order details. Document the release convention in the README.
    Claude-Session: https://claude.ai/code/session_01NasVGexyu8x6URgbCxJCUj
2026-11-08 Pixel PCB v0.1: record the JLCPCB order
    Fill in the v0.1 manifest's order section (order numbers, options, cost,
    placement preview result). Economic assembly is single-sided, so J1/J2 are
    hand-soldered on v0.1; add a TBD for the 22-board run. The order form had no
    order-number location option, so the board was ordered with Remove Mark.
    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
2026-11-09 House holder: right-angle header draft (checkpoint)
    Add the "House holder" spec to the README and a draft OpenSCAD model in
    hardware/holder/: a clip ring with in-plane flexing arms (coupon variants
    A-D and test rings), a swiveling carrier for the PCB and flat-lying plugs,
    a Pixel PCB mock, and an assembly view with overlap checks.
    Also add the source measurements: the 2026 scanned notes, the 2021
    spreadsheet, and the two 2021 plug gcode files.
    Checkpoint before switching to vertical headers, which put the PCB inside
    the house. Known issue: the arms form a tall tube that blocks much of the
    light.
2026-11-09 House holder: switch to vertical headers, PCB inside the house
    Redraft the holder as one printed piece. The PCB snaps onto three posts
    above the clip ring's arms, LEDs up, so the hole's rim no longer blocks the
    light. Both plugs hang straight down through the hole, and a cable tie
    through the flange straps the cables to its underside.
    - clip.scad: drop the carrier groove, add arm_rot and an arm-sweep model
    for clearance checks, 40 degree lead-in.
    - holder.scad: posts with PCB ledges and hook lips, flange tie slots.
    - pixel_mock.scad: v0.1 board with vertical headers and hanging plugs.
    - assembly.scad: holder_mock and sweep_mock overlap checks.
    - carrier.scad removed (kept at tag holder-ri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
2026-11-09 House holder: coupon v0.1 print package
    Add rendered STLs for the clip ring coupon (variants A-D) and the four test
    rings, with a MANIFEST recording the source commit, OpenSCAD version, file
    hashes, variant parameters and print settings. Point the README test plan
    at it.
    Claude-Session: https://claude.ai/code/session_01NasVGg6VN5ZHrVaXxsKN1B
